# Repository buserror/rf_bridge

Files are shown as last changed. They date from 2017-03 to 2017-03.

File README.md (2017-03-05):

# Home Automation: MQTT <-> RF 433Mhz Bridge for switches and sensors.
This project implements a RF bridge for 433Mhz devices. The idea is to have a small AVR do the mod/demod and send diggested messages on it's serial port to a linux box for processing; in this case bridging sensors and switches to a MQTT broker.

This was made to interface my cheap RF433 gizmoz (wall switches, outlets, temperature sensors etc) to the home automation, and ultimately the Amazon echo/Alexa.

The fact the AVR does all the sensitive bits means the linux program doesn't eat a lot of CPU and can concentrate on the applicative parts, which is the MQTT bridging.

<p align="center">
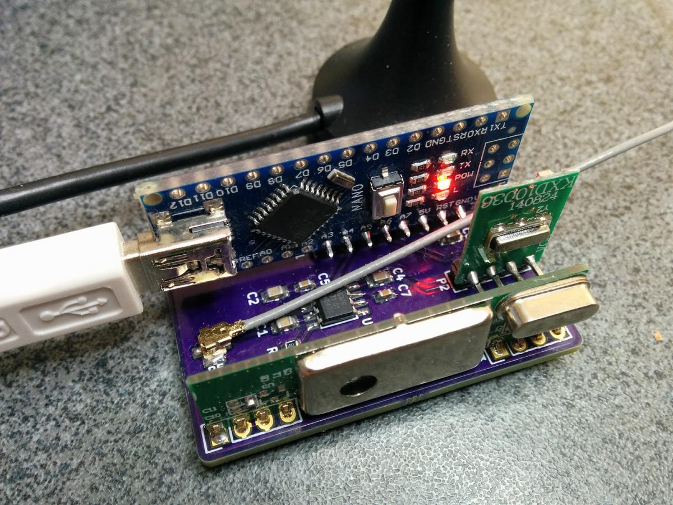
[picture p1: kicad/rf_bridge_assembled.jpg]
Finished project

<p align="center">Finished Project (Minus case)</p>
</p>

## The AVR Bits
The firmware can run on anything with about 2KB of SRAM (currently uses <1300 bytes), and a clock of 16Mhz. The firmware 'samples' the RF signal from the 433 module at about 64khz and tries to detect edges, then regular pulses, then does some decoding until a 'long low pulse', and forwards it on.

The firmware can also transmit (altho this part isn't finished, only ASK is working for now) using the same message format. The code doesn't try to be too clever and has a 'raw' mode it can be switches into to forward raw pulses straight to the host for analysis. 

The firmware is capable of decoding both Amplitude-Shift Keying (ASK) and manchester encoding. It's completely frequency/pattern independent and continuously search for signal in the noise before applying some filtering and hopefully forward the whole diggested message onward.

Also, I wanted to publish a firmware that looks marketedly different from the typical arduidiot[0] firmware that is all bloaty, synchronous and so on. This firmware uses coroutines, is completely asynchronous and allows the AVR to be in sleep mode most of the time. *This* is he way I do embedded; use a tick clock of any frequency (here, I use the sampling clock) and derivate everything else from it, and sleep in between ticks when you no longer need the CPU.

The only bit that is not synchronous to that tick mark is the UART, it's all interrupt driven, and it's nicely isolated using biggish FIFOs so it's unlikely to become blocking.

[0]: Arduidiot is my name for the well known boards. Since a few years back when they started suing each others for the name, I decided my version of the name was a lot more appropriate.

### Message format
A Typical message will be sent to the host like this, for a dumb switch:

    MA:40553300#19!3f*36

This is a message that already has been decoded as ASK encoding, has 0x19 bits, the clock duration was 0x2f timer clock cycle per bit, and the checksum was 0x36.

A more involved message would be:

    MM:0028b4206b0b38c0#40!3f*ff

This one has 'M'anchester encoding, 0x40 bits with 0x3f/2 timer ticks per bits.

The reason the timer clock is returned is to be able to reply the message back. Currently you can 'replay' ASK messages by just sending them back to the serial port. They will be replayed 3 times.

## The Linux Bits
The linux bit sits on the serial port, reads diggested messages and 'maps' them to MQTT messages. For dumb on/off switches it uses a file containing the mapping; but there is an extra decoder for the temperature/humidity sensor. The mapping is'nt terribly clever and use a flat file. 

The linux process uses libmosquitto to connect to a MQTT broker. I might try to do away with the libmosquitto requirement, as I don't think I need all the features (and footprint) it brings. I just need a unsecured connection to a broker, and let the broker be 'clever' and do encryption bridging if needs be.

The linux bit also subscribes to the mapped messages, and when it received a MQTT notification that hasn't been sent by itself, it just passes it on to the AVR board for transmisssions. That means you can have a Dashboard with switches, or use Amazon Alexa etc to send the messages on the RF link. No need for a web interface etc, just use MQTT. I personally use Node-Red to do the Alexa Logic bits.

The program can run on pretty much anything, it uses very very little resources, so a Raspberi Pi or anything else will work just fine!

## The Hardware Bits
Note: The hardware has [it's own page](kicad/README.md).

For prototyping I used an Arduino Mega and a RF433 receiver + transmitter. I ended up using 2 antennas separated by about 20cm on the prototype, it works, even if the receiver is a bit overwelmed for a little while after I transmit anything. It otherwises requires no extra hardware. The only thing I did was add a 100R resistor in series with the receiver output, as I was seeing a lot of ringing on the oscilloscope.

The 'real' hardware will be an Arduino nano v3.0 with an Atmega 328p. Powered via the USB port. I've designed a board using Kicad already, and the PCBs are on the way. https://oshpark.com/shared_projects/ZqEOBR2t
Hardware uses a NXP RF switch for sharing an antenna in half-duplex, and apart from a bit of filtering that's about it! More later.

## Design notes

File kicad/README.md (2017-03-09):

#Hardware: rf_bridge

Version 1.x of the hardware uses very little hardware. You need:

  * An Arduino with ~1.5KB SRAM and bout 6KB flash, and runs at least at 16Mhz.
  * A cheap 433Mhz receiver module
  * A cheap 433Mhz transmitter module

The pcb also has a RF switch to be able to share the antenna. The prototype didn't have that and used 2 17cm pieces of wire, and it worked just fine, so it's not *stricly* needed. The hardware here is made to be a neater small package with pigtail connector to a 'proper' antenna.

<p align="center">
Finished project
<p align="center">Finished Project</p>
</p>
The PCB is very simple, the arduino I picked is a Nano, and it's mounted vertically with the 433 bits, so the result is quite compact.
<p align="center">
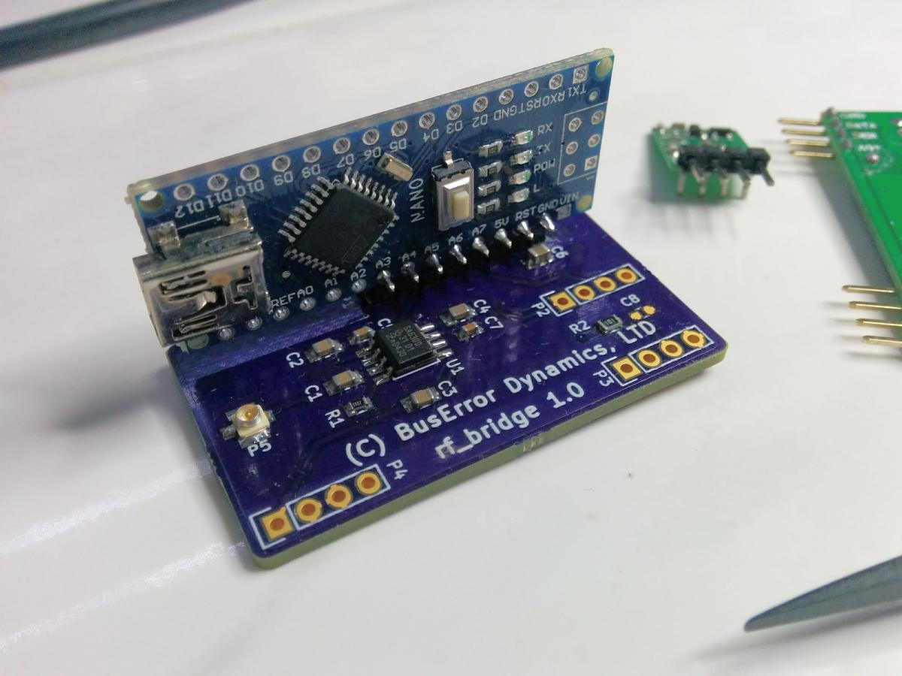
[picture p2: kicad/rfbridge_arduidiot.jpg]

<p align="center">Note the 90 Header is offset by <b>one pin</b>.</p>
</p>

  * You can find the schematic as a [.PDF in this directory](rf_bridge_schematics.pdf). 
  * The PCB was ordered from OSHPark ($9 for 3) -- You can order PCBs directly from [this link](https://oshpark.com/shared_projects/YTztWeXs).

##The BOM:

|Ref.|Value|Description
|----|---|---|
|C1,C2,C3,
C4,C7|10nF|0603 Caps.|
|C5|100nF|0604 Cap|
|C6|4.7uF|0805 Capacitor (Optional)|
|C8|10pF|0603 Cap (Optional)|
|P1|Nano|[Arduino Nano v3.0](https://www.amazon.co.uk/gp/product/B015MGHH6Q). Use 90 headers for mounting. Only use a 8 pins section of them, and the headers are NOT soldered from the first pin, but from the pin marked GND on the Nano, *NOT the VIN pin*.|
|P2|RF_TX|Both the TX and the RX comes from eBay.|
|P3,P4|RF_RX|[These](http://www.ebay.co.uk/itm/331805856615) are the exact modules I used|
|P5|U.FR|SMT 'pigtail' antenna Connector [Hirose U.FL](http://uk.farnell.com/hirose-hrs/u-fl-r-smt-1-10/rf-coaxial-u-fl-straight-jack/dp/1688077)|
|R1|10K|0603 Pulldown|
|R2|100|0603 Filtering, use anytime you like here even R0|
|U1|SA630|SOIC8. RF Antenna Switcher. [NXP SA630D](http://uk.farnell.com/nxp/sa630d-01-112/rf-switch-spdt-dc-1ghz-soic-8/dp/2400605) |

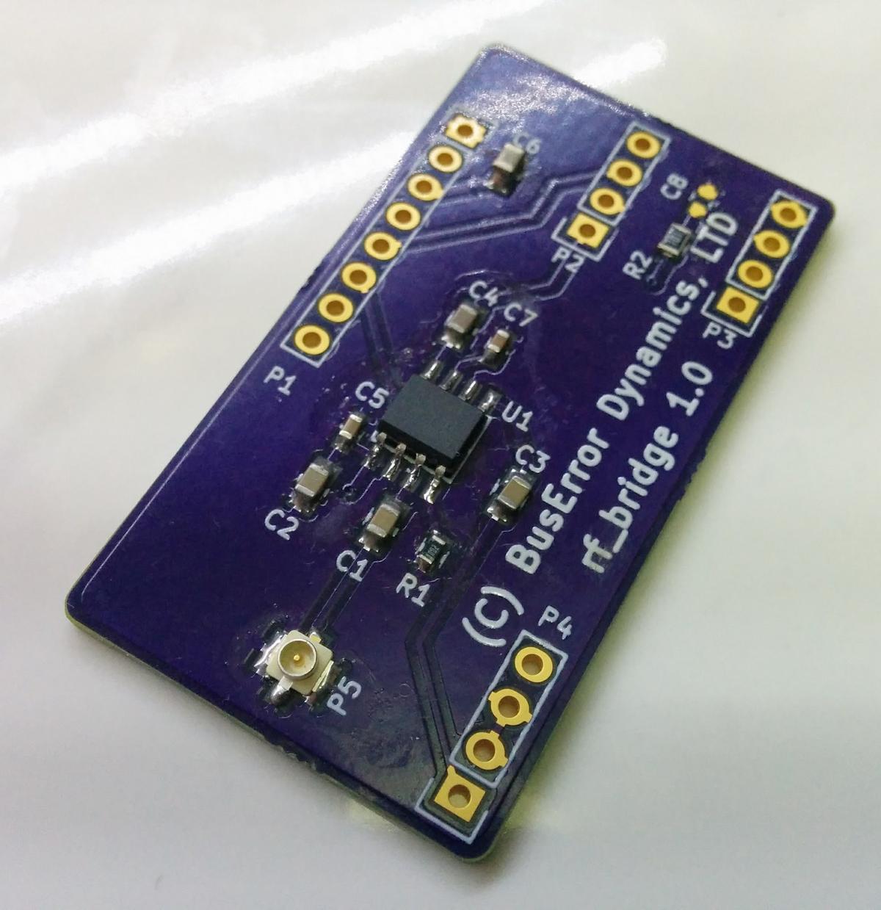
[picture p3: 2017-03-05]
kicad/rfbridge_reflowed.jpg

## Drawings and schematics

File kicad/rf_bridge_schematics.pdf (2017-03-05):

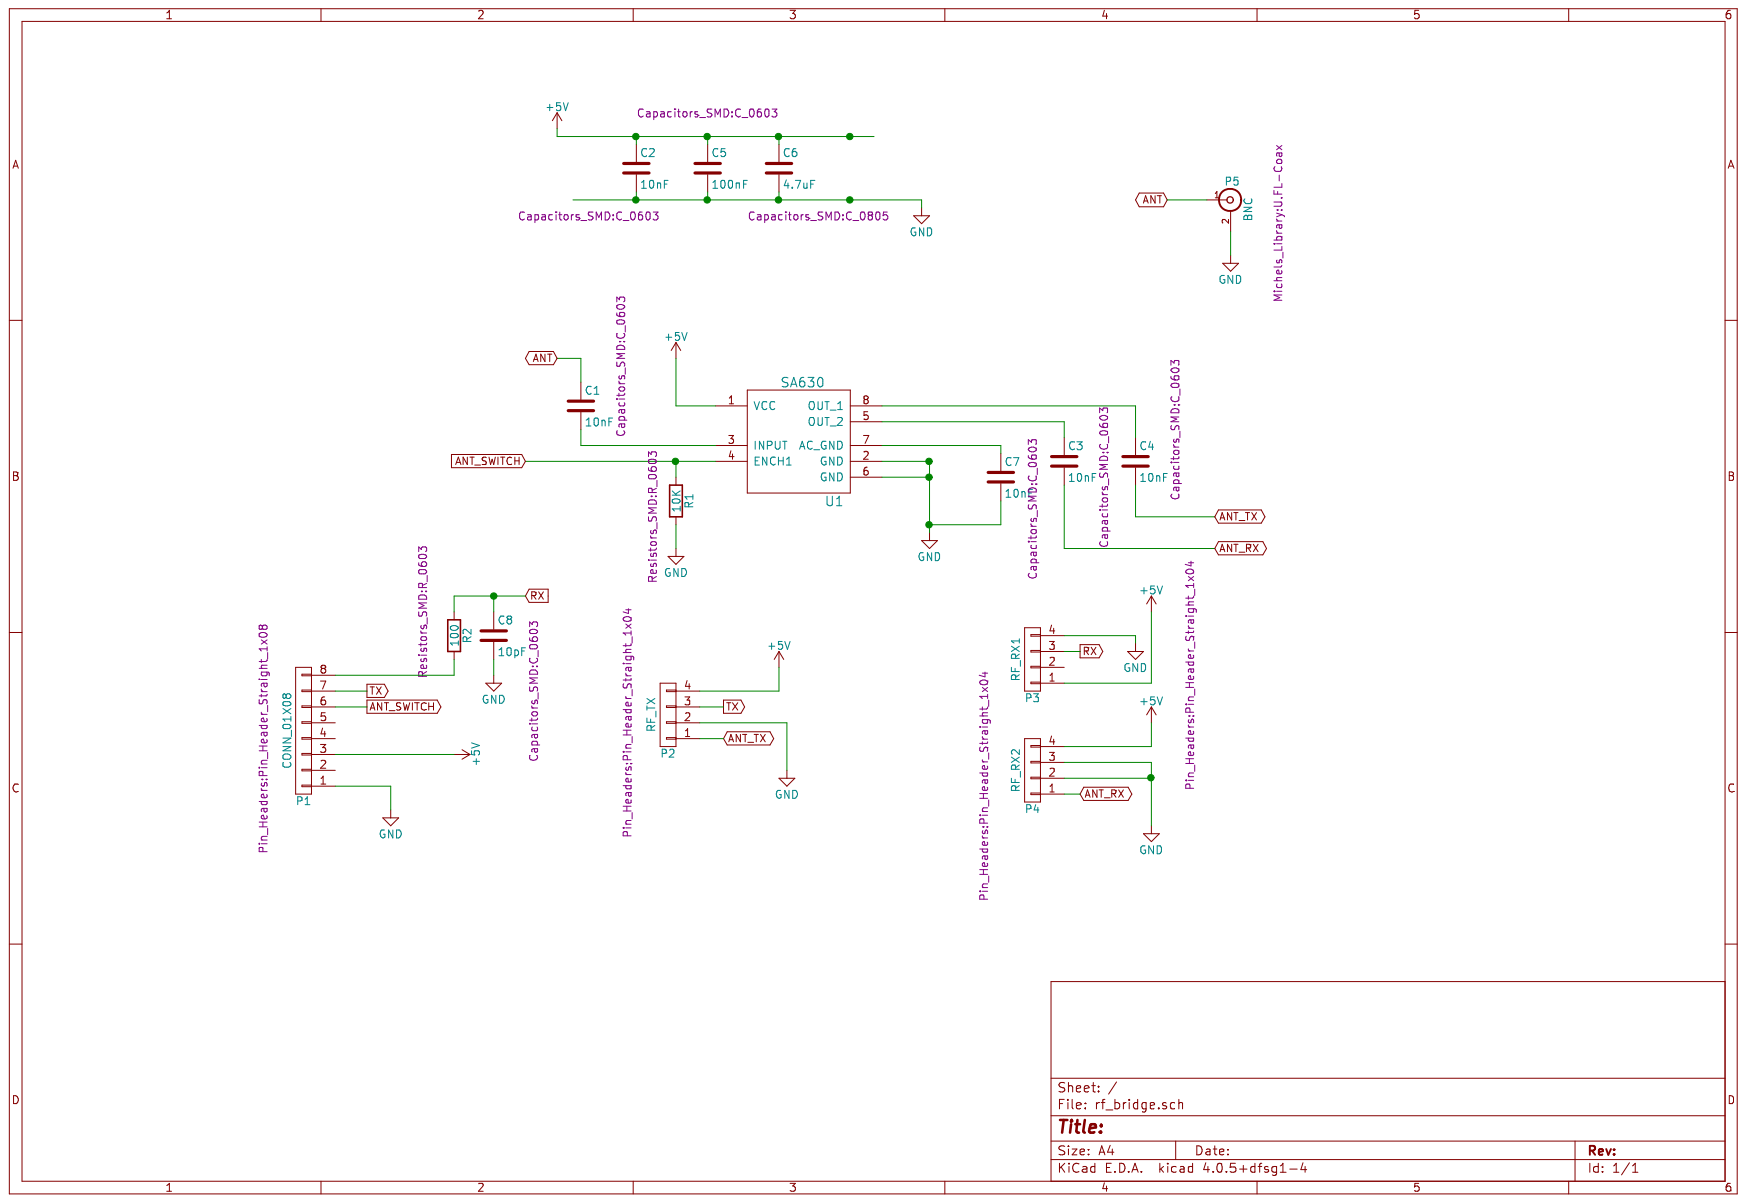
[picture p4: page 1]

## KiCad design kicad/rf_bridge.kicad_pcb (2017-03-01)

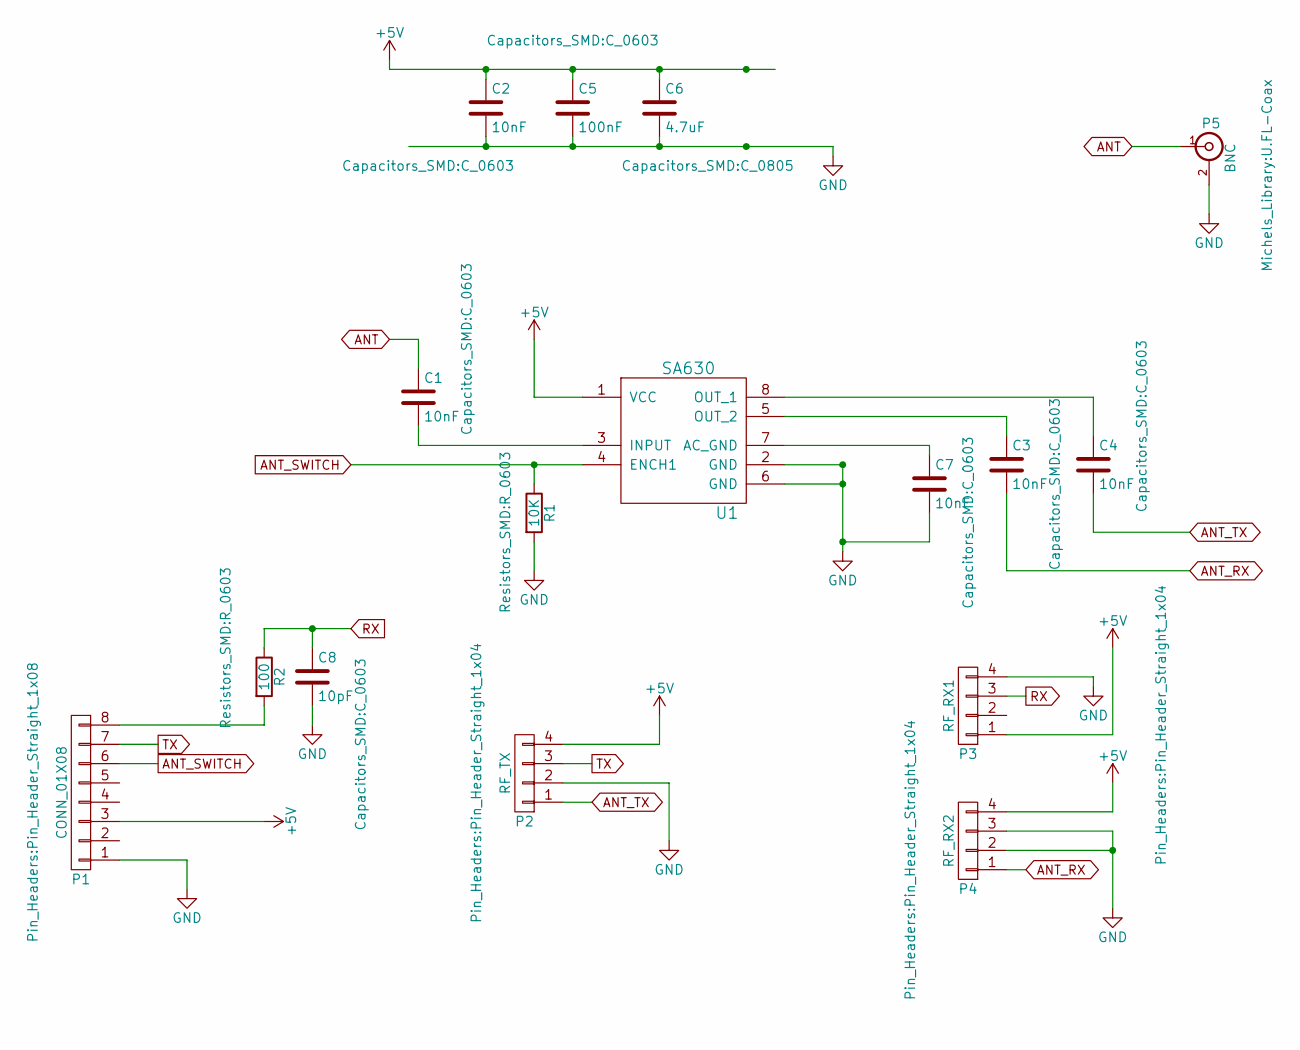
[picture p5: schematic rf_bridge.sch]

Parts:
C1, C2, C3, C4, C7: 10nF; C_0603
C5: 100nF; C_0603
C6: 4.7uF; C_0805
C8: 10pF; C_0603
P1: CONN_01X08; Pin_Header_Straight_1x08
P2: RF_TX; Pin_Header_Straight_1x04
P3: RF_RX1; Pin_Header_Straight_1x04
P4: RF_RX2; Pin_Header_Straight_1x04
P5: BNC; U.FL-Coax
R1: 10K; R_0603
R2: 100; R_0603
U1: SA630; SOIC-8-N

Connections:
+5V: C2.1, C5.1, C6.1, P1.3, P2.4, P3.1, P4.4, U1.1 (VCC)
ANT: C1.1, P5.1 (In)
ANT_RX: C3.2, P4.1
ANT_SWITCH: P1.6, R1.1, U1.4 (ENCH1)
ANT_TX: C4.2, P2.1
GND: C2.2, C5.2, C6.2, C7.2, C8.2, P1.1, P2.2, P3.4, P4.2, P4.3, P5.2 (Ext), R1.2, U1.2 (GND), U1.6 (GND)
unnamed: C1.2, U1.3 (INPUT)
unnamed: C3.1, U1.5 (OUT_2)
unnamed: C4.1, U1.8 (OUT_1)
unnamed: C7.1, U1.7 (AC_GND)
unnamed: P1.8, R2.2
RX: C8.1, P3.3, R2.1
TX: P1.7, P2.3

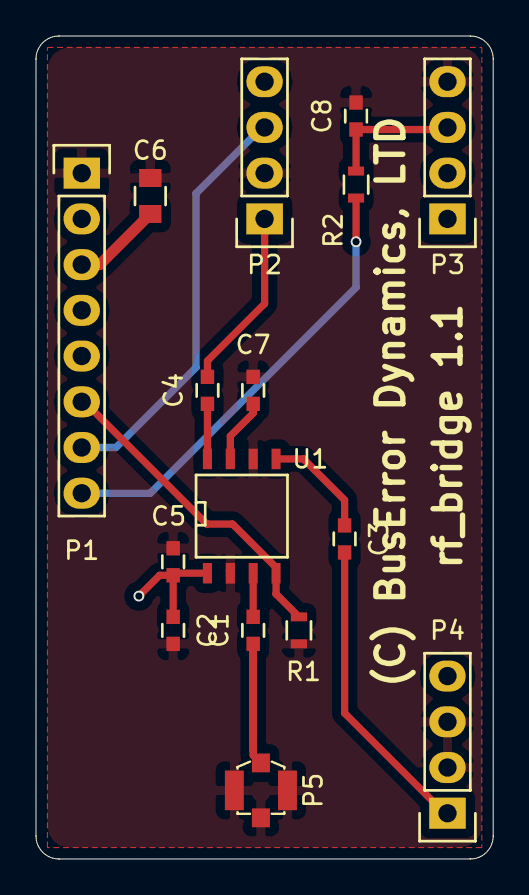
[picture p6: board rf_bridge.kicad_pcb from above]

Board: 2 copper layers, 25.4 x 45.7 mm, 16 parts (0 on the bottom side), 13 nets.

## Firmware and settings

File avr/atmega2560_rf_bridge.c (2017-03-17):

/*
	RF to MQTT Bridge.

	Copyright 2017 Michel Pollet <buserror@gmail.com>

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
    You should have received a copy of the GNU General Public License
    along with this program.  If not, see <http://www.gnu.org/licenses/>.
 */

#include <avr/io.h>
#include <stdio.h>
#include <avr/interrupt.h>
#include <avr/sleep.h>
#include <avr/pgmspace.h>

/* local includes */
#define CR_MAIN
#include "avr_cr.h"

#ifdef SIMAVR
/* simavr specific, not strictly needed until simulating */
#include "avr_mcu_section.h"
AVR_MCU(F_CPU, "atmega2560");

AVR_MCU_VCD_PORT_PIN('H', 4, "TX"); // transmitter
AVR_MCU_VCD_PORT_PIN('H', 5, "RX"); // receiver
AVR_MCU_VCD_PORT_PIN('H', 3, "Antenna"); // pin_Antenna
AVR_MCU_EXTERNAL_PORT_PULL('H', (1 << 3), 0); // pulldown here
AVR_MCU_VCD_PORT_PIN('E', 4, "Debug0"); // Debug0
AVR_MCU_VCD_PORT_PIN('E', 5, "Decode"); // Debug1
AVR_MCU_VCD_PORT_PIN('G', 5, "Sync"); // Debug2

AVR_MCU_VCD_IRQ(TIMER0_COMPA);
AVR_MCU_VCD_IRQ(TIMER0_COMPB);
AVR_MCU_VCD_IRQ(USART0_UDRE);
//AVR_MCU_VCD_IRQ_PENDING(USART0_UDRE);
//AVR_MCU_VCD_ALL_IRQ_PENDING();

const struct avr_mmcu_vcd_trace_t _mytrace[]  _MMCU_ = {
	{ AVR_MCU_VCD_SYMBOL("UDR0"), .what = (void*)&UDR0, },
	{ AVR_MCU_VCD_SYMBOL("UDRE0"), .mask = (1 << UDRE0), .what = (void*)&UCSR0A, },
	{ AVR_MCU_VCD_SYMBOL("UDRIE0"), .mask = (1 << UDRIE0), .what = (void*)&UCSR0B, },
	{ AVR_MCU_VCD_SYMBOL("GPIOR1"), .what = (void*)&GPIOR1, },
	{ AVR_MCU_VCD_SYMBOL("GPIOR2"), .what = (void*)&GPIOR2, },
	/* we subvert these two registers as debug for simavr traces */
	{ AVR_MCU_VCD_SYMBOL("Pulse"), .what = (void*)&SPSR, },
	{ AVR_MCU_VCD_SYMBOL("Duration"), .what = (void*)&SPCR, },
};

#endif

#include "rf_bridge_common.h"
#include "rf_bridge_pins.h"

extern FILE mystdout;

int main() __attribute__((naked));

int main()
{
	stdout = &mystdout;

	// LED on
	pin_output(pin_LED);
	pin_set_to(pin_LED, 0);

	// http://www.nongnu.org/avr-libc/user-manual/group__util__setbaud.html
	UCSR0A |= (1 << U2X0);
	UCSR0C = (3 << UCSZ00); // 8 bits
	UBRR0H = 0;
	UBRR0L = 0x10;
	// enable receiver, transmitter and the interrupts
	UCSR0B |= (1 << UDRIE0) | (1 << RXCIE0) | (1 << RXEN0) | (1 << TXEN0);

	// https://et06.dunweber.com/atmega_timers/
	// 16mhz -> 32.7k timer for resampling
	TCCR0A = (1 << WGM01); // CTC mode
	TCCR0B = (1 << CS01);
	OCR0A = 0x3d / 2;
	OCR0B = 0x3d / 2;

#ifdef DEBUG
	// debug pins for logic analyser
	pin_output(pin_Debug0);
	pin_output(pin_Debug1);
	pin_output(pin_Debug2);
	pin_output(pin_Debug3);
#endif

	rf_bridge_run();
}

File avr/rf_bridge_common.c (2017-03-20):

/*
	RF to MQTT Bridge.

	Copyright 2017 Michel Pollet <buserror@gmail.com>

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
    You should have received a copy of the GNU General Public License
    along with this program.  If not, see <http://www.gnu.org/licenses/>.
 */

#include <avr/io.h>
#include <stdio.h>
#include <avr/interrupt.h>
#include <avr/sleep.h>
#include <avr/pgmspace.h>

#include "avr_cr.h"
#include "rf_bridge_uart.h"
#include "rf_bridge_pins.h"
#include "rf_bridge_common.h"

#define STACK_DEBUG

#ifdef STACK_DEBUG
#include <string.h> // memset
#endif

#define ARRAY_SIZE(xx) (sizeof(xx)/sizeof(xx[0]))

#ifdef DEBUG
#define D(w) w
#else
#define D(w)
#endif

/*
 * Main firmware states; always fallback to SyncSearch
 */
enum {
	state_SyncSearch = 0,
	state_Decoding_ASK,
	state_Decoding_OOK,
	state_Decoding_Manchester,
	state_DecodeRawPulses,
	state_DecodeDone,
	state_ReceivingCommand,
};
volatile uint8_t	running_state = state_SyncSearch;

/* Flag: Are we displaying raw pulses, or already decoded messages */
struct {
	uint8_t display_pulses: 1, display_stacks: 1;
} flags = {
	.display_pulses = 0,
};

volatile uint8_t tickcount = 0;

/*
 * everything is pretty much geared to use uint8_t integer overflow
 * naturally, without having to worry about boundaries etc, so the pulse
 * count buffer is more or less fixed at that size, and everything else
 * like cursors will also use the same 8 bits overflows.
 */
volatile uint8_t pulse[256][2];		// circular buffer of pulse durations
volatile uint8_t current_pulse = 0;	// current 'filling' cursor
volatile uint8_t msg_start = 0,
				msg_end = 0;			// markers for the decoders

/*
 * Transceiver state; we are half duplex, can't receive and transmit, as
 * it'd be rather silly to receive back garbled version of what we send.
 * (garbled because of the proximity of the transmitter)
 */
enum {
	mode_Idle = 0,
	mode_Receiving,
	mode_StartTransmit,
	mode_Transmitting,
};
volatile uint8_t transceiver_mode = mode_Receiving;

const uint8_t timer_mask = (1 << OCIE0A) | (1 << OCIE0B);

static inline void disable_transceiver()
{
	transceiver_mode = mode_Idle;
	pin_clr(pin_Antenna);
	TIMSK0 &= ~timer_mask;
}

static inline void enable_receiver()
{
	if ((TIMSK0 & timer_mask) == (1 << OCIE0A))
		return;
	TIMSK0 &= ~timer_mask;
	pin_clr(pin_Antenna);
	transceiver_mode = mode_Receiving;
	TIMSK0 |= (1 << OCIE0A);
}

static inline void enable_transmitter()
{
	if ((TIMSK0 & timer_mask) == (1 << OCIE0B))
		return;
	TIMSK0 &= ~((1 << OCIE0A) | (1 << OCIE0B));
	pin_set(pin_Antenna);
	transceiver_mode = mode_StartTransmit;
	TIMSK0 |= (1 << OCIE0B);
}

#define MAX_TICKS_PER_PHASE 255

/*
 * This is the 'sensitive' part here. Nothing fancy, everything needs
 * to be quick as the frequency of the timer is quite high; so in receive
 * mode we just do some filtered edge detection (cheaply).
 */
ISR(TIMER0_COMPA_vect)	// handler for Output Compare 0 overflow interrupt
{
	static uint8_t bit = 0;			// bool
	static uint8_t b;

	b = pin_get(pin_Receiver);

	/* increment the pulse count for the phase (bit) we are in */
	if (pulse[current_pulse][b] < MAX_TICKS_PER_PHASE)
		pulse[current_pulse][b]++;
	/* if raising edge, switch pulse counter to the next one */
	if (!bit && b) {
#if defined(SIMAVR) && defined(M2560)
			D(SPCR = pulse[current_pulse][0]);
#endif
		/* if tiny pulse, just ignore it */
		if (pulse[current_pulse][0] > 20 || pulse[current_pulse][1] > 20)
			current_pulse++;
		pulse[current_pulse][0] = pulse[current_pulse][1] = 0;
	}
#if defined(SIMAVR) && defined(M2560)
	else if (bit && !b) {
			D(SPCR = pulse[current_pulse][1];)
	}
	D(SPSR = current_pulse;)
#endif
	bit = b;
//	D(pin_set_to(pin_Debug0, bit);)

	tickcount++;
}

/*
 * On transmit we just go over the buffer setting the output state as we
 * go along, decrementing remaining pulses as we go forward.
 * The 'current' pulse is mirrors, so the message can be replayed.
 */
ISR(TIMER0_COMPB_vect)	// handler for Output Compare 1 overflow interrupt
{
	static uint8_t bit = 0;			// bool
	static uint8_t tp[2];			// temp pulse

	switch (transceiver_mode) {
		case mode_Transmitting: {
			if (tp[bit])
				tp[bit]--;
			if (tp[bit])
				break;
			bit = !bit;
			if (bit) {
				current_pulse++;
				tp[0] = pulse[current_pulse][0];
				tp[1] = pulse[current_pulse][1];
				if (current_pulse == msg_end) {
					transceiver_mode = mode_Idle;
					bit = 0; // we're done, return to 0
				} else
					bit = !!tp[1]; // hande case when new phase(1) is zero
			}
			pin_set_to(pin_Transmitter, bit);
		}	break;
		case mode_StartTransmit: {
			bit = 1;	// start phase is one.
			transceiver_mode = mode_Transmitting;
			current_pulse = msg_start;
			tp[0] = pulse[current_pulse][0];
			tp[1] = pulse[current_pulse][1];
			pin_set_to(pin_Transmitter, 1);
		}	break;
	}

	tickcount++;
}

// absolute value substraction for durations etc
static uint8_t abs_sub(uint8_t v1, uint8_t v2) {
	return v1 > v2? v1 - v2 : v2 - v1;
}
// overflow substraction for the counters
uint8_t ovf_sub(uint8_t v1, uint8_t v2) {
	return v1 > v2 ? 255 - v1 + v2 : v2 - v1;
}

/* used by the syncsearch, and used by the manchester decoder too */
uint8_t syncduration = 0;
uint8_t chk = 0, byte = 0;
uint8_t bcount = 0;
uint8_t msg_type = 'P';

/*
 * stuff the next bit in the 8 bits buffer, and output it when full.
 * With enough memory, we could use a much larger buffer and do the print
 * at the end, but it's not really necessary as we send it all to a
 * computer with much more resources.
 */
static void stuffbit(uint8_t b, uint8_t last) {
	uint8_t bn = bcount % 8;
	byte |= b << (7 - bn);
	bcount++;
	if (last || bn == 7) {
		chk += byte;
		printf_P(PSTR("%02x"), byte);
		byte = 0;
	}
}

AVR_CR(cr_syncsearch_backward)
{
	uint8_t pi = current_pulse;

	do {
		while (pi == current_pulse || running_state != state_SyncSearch) {
			if (running_state == state_SyncSearch) {
				if (!uart_rx_isempty(&uart_rx))
					running_state = state_ReceivingCommand;
			}
			cr_yield(0);
		}
		uint8_t gotsync = 0;
		while (pi != current_pulse && !gotsync) {
			gotsync = pulse[pi][0] >= MAX_TICKS_PER_PHASE;

			if (gotsync)
				msg_end = pi;
			pi++;
		}
		if (!gotsync)
			continue;
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

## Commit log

2017-02-05 Embedded firmware update
    + Replaced the command/message parser.
    + Changed the message format a bit, now uses '#' for bitcounts. This
    allow the aprser to look for a character prefix any any place and know
    what's behind it.
    + Added some debug code to dump the coroutine stack usage data, tweaked
    the stack values accordingly.
    [arduidiot.h, rf_bridge_common.c]
2017-02-15 Reworked linux parser, again
    Getting there. parser now parametric, loaded message file uses it.
    [rf_bridge_common.c]
2017-02-17 Added traces for simavr
    No functional changes
2017-02-19 Add kicad project for the PCB for the 'final' assembly.
    Designed the carrier board for the final project, and shipped it to
    oshpark...
    First project ever with Kicad, to replace my old trusted Eagle.
    [rf_bridge.kicad_pcb, rf_bridge.sch]
2017-02-21 Small update, fixed the kicad project, tweaked comments
    Bit of polishing up. Also added a .pdf of the schematic for reference.
    [rf_bridge.sch]
2017-02-22 Pre work on the PIR sensor detect
    The PIR sensor I've sources don't send equal pulses at the start of
    their manchester phrases..So I need to adapt the scanning code for that.
    Captured a trace for this, and started to tweak the scanning code to
    adap to this.
2017-02-23 Added an VCD output trace for validation
    Output of simavr. This shows the firmware starting up, sending a
    message, the *OK and terminating.
2017-03-01 pcb: A few tweaks for next version
    Changed the footprint of the 10nF's to 0603, as I've discovered I have a
    bout 1Kg of them.
    Also changed pinout! Silly me, I used A6 and A7 pins on the arduidiot,
    but these are ADC only, no digital logic. So luckily I had hooked up two
    'spare' pins, so I switched to these instead.
    Also, the rest of the PCB has beem tested, and the switch is defaulting
    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
    [rf_bridge.kicad_pcb, rf_bridge.sch]
2017-03-02 avr: Now use two timers
    Turns out it takes a lot less cycles to split the job between the two
    comparators, running at the same frequency.
    Since they don't run together, they do less tests.
    Also remove edge detection filtering, turns out nice noisy pulses are
    easy to filter out beforehand before storing them.
    And various other bits
2017-03-03 Increased the maximum ticks per phase
    And tweaked the sync code. Turns out the PIR sensor send their stream
    with very low bitrate, and the pulses were longer than the maximum 127
    that normally tells us it's an end of message. Doh.
2017-03-05 avr: Quite a few changes to handle slow bitrate PIRs
    The PIR sensors are so slow they were overflowing the 7 bits I used for
    pulsecount. So now I use the full 8 bits, and I also tweaked the scanner
    to handle pulse train that don't start with 6-8 identical pulses.
    Also, resized stacks, they are now smaller since we don't one big IRQ,
    but two smaller ones.
2017-03-06 Some more scanner tweaks
    Check manchester header's for some consistency before printing
2017-03-16 Revamped config file format
    Now have sections for mqtt, sensors, switches and PIRs (TODO)

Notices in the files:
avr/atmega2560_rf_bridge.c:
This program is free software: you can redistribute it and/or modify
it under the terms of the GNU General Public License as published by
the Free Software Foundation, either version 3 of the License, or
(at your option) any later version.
